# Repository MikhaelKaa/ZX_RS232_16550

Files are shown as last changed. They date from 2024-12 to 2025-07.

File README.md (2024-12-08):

# ZX RS232 на базе 16c550

## Описание
На данный момент сделан прототип.
top Прототип, вид на детали
top Прототип, вид на монтаж

## Программное обеспечение

## Схема подключения

## Начало работы

## Сборка устройства

## Лицензия

## Авторы

Оригинальная идея и порты - Михаил Кондратьев.

Прошивка cpld, схема и трассировка - Михаил Каа

## Благодарности

AnissimGimmervert

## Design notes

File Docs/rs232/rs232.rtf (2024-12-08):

Последовательный интерфейс RS-232. “Схема Кондратьева”.
ZX-MiltiCard v1.2 by Caro (Камиль Каримов).
Автор сего опуса jdigreze (Игорь Афонькин).
1. Общие положения
В состав многофункционального интерфейса ZX-MultiCard входит последовательный интерфейс стандарта RS-232C, включенный по схеме Кондратьева. В пространстве ввода-вывода компьютера ZX Spectrum устройство имеет базовый адрес #F8EF (63727).
Контроллер последовательного интерфейса является программируемым устройством, однако, следует отметить, что данная реализация не использует поддержку всех функций, заложенных в оригинале, построенном на базе кристалла i8250, используемого в семействе IBM PC, что, однако, не идет в ущерб в большинстве применений.
2. Описание внутренних регистров
С программной точки зрения, контроллер имеет несколько управляющих регистров, доступных через порты ввода-вывода компьютера ZX Spectrum. Всего в устройстве предусмотрено 8 портов ввода-вывода, два из которых оставлены для совместимости с оригиналом, и не влияют на работу контроллера.
Таблица соответствия регистров управления адресам портов ввода-вывода
№ рег. | Адрес | DLAB | Доступ | Наименование | Описание
0 | #F8EF | 0 | RW | REG_IO | Регистр данных
0 | #F8EF | 1 | W | REG_DIV_L | Младшая часть делителя
1 | #F9EF | 0 | - | REG_IRQ_ENABLE | Не используется
1 | #F9EF | 1 | W | REG_DIV_H | Старшая часть делителя
2 | #FAEF | 0 | - | REG_IRQ_IDENT | Не используется
3 | #FBEF | 0 | W | REG_LINE_CTRL | Управление конфигурацией
4 | #FCEF | 0 | W | REG_MDM_CTRL | Управление дополнительной линией
5 | #FDEF | 0 | R | REG_LINE_STATUS | Состояние приемопередатчика
6 | #FEEF | 0 | R | REG_MDM_STATUS | Состояние дополнительной линии
7 | #FFEF | 0 | - | REG_WORK_REG | Не используется
Примечание:
- Соответствие номера регистра адресу порта ввода-вывода устанавливается по формуле: RegisterAddress = BasicAddress + #100 x RegisterNumber, где RegisterAddress – адрес нужного регистра, BasicAddress – базовый адрес устройства (#F8EF), RegisterNumber – номер регистра для которого рассчитывается адрес;
- DLAB – 7 бит регистра управления конфигурацией (REG_LINE_CTRL);
- Порты #F8EF и #F9EF подключены к разным регистрам в зависимости от значения DLAB
- Режимы доступа к регистрам описаны условно

#F8EF - REG_IO (Регистр данных приемопередатчика)

Доступ к регистру осуществляется при DLAB = 0. При записи байта данных в этот регистр инициализируется передатчик последовательного интерфейса. Принятый байт данных получаем чтением из регистра. Перед работой с этим регистром требуется анализ регистра состояния приемопередатчика (#FDEF – REG_LINE_STATUS).

#F8EF – REG_DIV_L, #F9EF – REG_DIV_H (Регистры делителя скорости)

Доступ к регистрам осуществляется при DLAB = 1. Значение делителя определяется по формуле DIV = 115200/SpeedInBaud, где SpeedInBaud – требуемая скорость в бодах. Например, для скорости 9600 бод, получим значение 12 (#000C), таким образом, старшая часть делителя будет равна нулю (REG_DIV_H = #00), а младшая часть делителя будет равна 12 (REG_DIV_L = #0C).
#FBEF – REG_LINE_CTRL (Регистр управления конфигурацией)

Номера битов | Назначение
7 | DLAB – переключение регистров в портах #F8EF и #F9EF
6 | При “1” – имитация обрыва линии
5 | При “1” передаваемый бит четности устанавливается постоянным, зависит от b3..4
3..4 | При “00” и “10” – бит четности не рассчитывается, “01” - нечетное, “11” - четное
2 | Кол-во “стоп-битов”: при “0” = 1, при “1” = 1,5 в режиме 5 бит данных, иначе = 2
0..1 | Число битов данных: при “00” = 5, при “01” и “10” = 6, при “11” = 8
Основное назначение регистра конфигурации, это установка параметров приемопередатчика, но в данной реализации контроллера установка “нестандартных” параметров невозможна, соответственно этот регистр используется только для установки значения DLAB (бит 7), используемого для переключения регистров в портах #F8EF и #F9EF. Однако, для совместимости программного обеспечения с оригинальной версией устройства необходимо устанавливать параметры “8N1”, которым соответствует число #03, записанное в этот регистр после установки параметров скорости обмена в регистрах REG_DIV_L и REG_DIV_H.
#FCEF – REG_MDM_CTRL (Регистр управления модемом)

Номера битов | Назначение
7..5 | Не используются (равны “0”)
4 | Не используется. В оригинале при установке “1” включает диагностический режим
3 | Не используется. В оригинале при установке “1” разрешает прерывания RS-232C
2 | Не используется.
1 | Управление линией RTS (Запрос на передачу)
0 | Не используется. В оригинале управляет линией DTR (Готовность комп. к работе)
Как видно из таблицы, в данном регистре используется лишь функция управления запросом на передачу данных. При использовании описываемого устройства с модемом, после запроса на передачу, требуется ожидание готовности модема по линии CTS (см. REG_MDM_STATUS).
#FDEF – REG_LINE_STATUS (Регистр состояния приемопередатчика)

Номера битов | Назначение
7 | Не используется (Равен “0”)
6 | При “1” – регистр передатчика пуст. Нет обрабатываемых данных.
5 | При “1” - сдвиговый регистр передатчика пуст. Можно передавать следующий байт.
4 | Не используется. В оригинале: “1” при обнаружении обрыва линии.
3 | Не используется. В оригинале: “1” при неверном стоп-бите.
2 | Не используется. В оригинале: “1” при ошибке четности.
1 | Не используется. В оригинале: “1” при потере предыдущего байта.
0 | Устанавливается в “1” при успешном приеме данных.
Данный регистр используется для контроля готовности приемопередатчика к обмену данными. Бит 0, содержащий “1”, сигнализирует об успешном приеме байта данных извне, и будет находиться в таком состоянии, пока компьютер не прочитает данные из регистра данных приемопередатчика (REG_IO). Бит 5, содержащий “1”, сигнализирует об успешной отправке байта данных. Бит 6, содержащий “1”, сигнализирует об отсутствии данных для передачи. Несмотря на явные отличия в назначении битов 5 и 6 данного регистра, фактически они выполняют одну и ту же функцию – сигнализируют о готовности контроллера к передаче следующего байта данных.

#FEEF – REG_MDM_STATUS (Регистр состояния модема)

Номера битов | Назначение
7 | Не используется. В оригинале отображает состояние линии DCD.
6 | Не используется. В оригинале отображает состояние линии RI.
5 | Не используется. В оригинале отображает состояние линии DSR.
4 | Отображает состояние линии CTS (Готовность модема к передаче).
3 | Не используется. В оригинале отображает изменение состояния линии DCD.
2 | Не используется. В оригинале отображает изменение состояния линии RI.
1 | Не используется. В оригинале отображает изменение состояния линии DSR.
0 | Не используется. В оригинале отображает изменение состояния линии CTS.
В данной реализации для контроля состояния модема используется только линия CTS, сигнализирующая о готовности модема к приему данных, в соответствии с запросом по линии RTS (см. REG_MDM_CTRL).
К сожалению, из-за отсутствия контроля индикатора вызова - линии RI, использование контроллера, для организации сервера удаленного доступа, фактически невозможно.
3. Порядок инициализации
Для подготовки контроллера к обмену данными через интерфейс RS-232С с внешними устройствами необходимо выполнить следующие действия:
1. Установить бит 7 (DLAB) регистра управления конфигурацией (#FBEF – REG_LINE_CTRL);
2. Установить значение скорости обмена в регистры делителя скорости (#F8EF – REG_DIV_L и #F9EF – REG_DIV_H);
3. Установить параметры “8N1” в регистр управления конфигурацией, при этом сбросить бит 7 (DLAB).
Пример настройки контроллера на скорость обмена 9600 бод из режима BASIC-48:
10 LET register = 3: LET value = 128: GO SUB 1000
20 LET register = 0: LET value = 12: GO SUB 1000
30 LET register = 1: LET value =0: GO SUB 1000
40 LET register = 3: LET value = 3: GOSUB 1000
50 REM параметры установлены
…
1000 OUT (63727 + 256 * register), value: RETURN
…

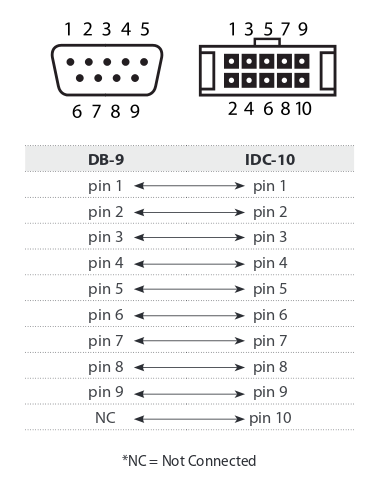
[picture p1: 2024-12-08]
Docs/media/plate9-pinout.png

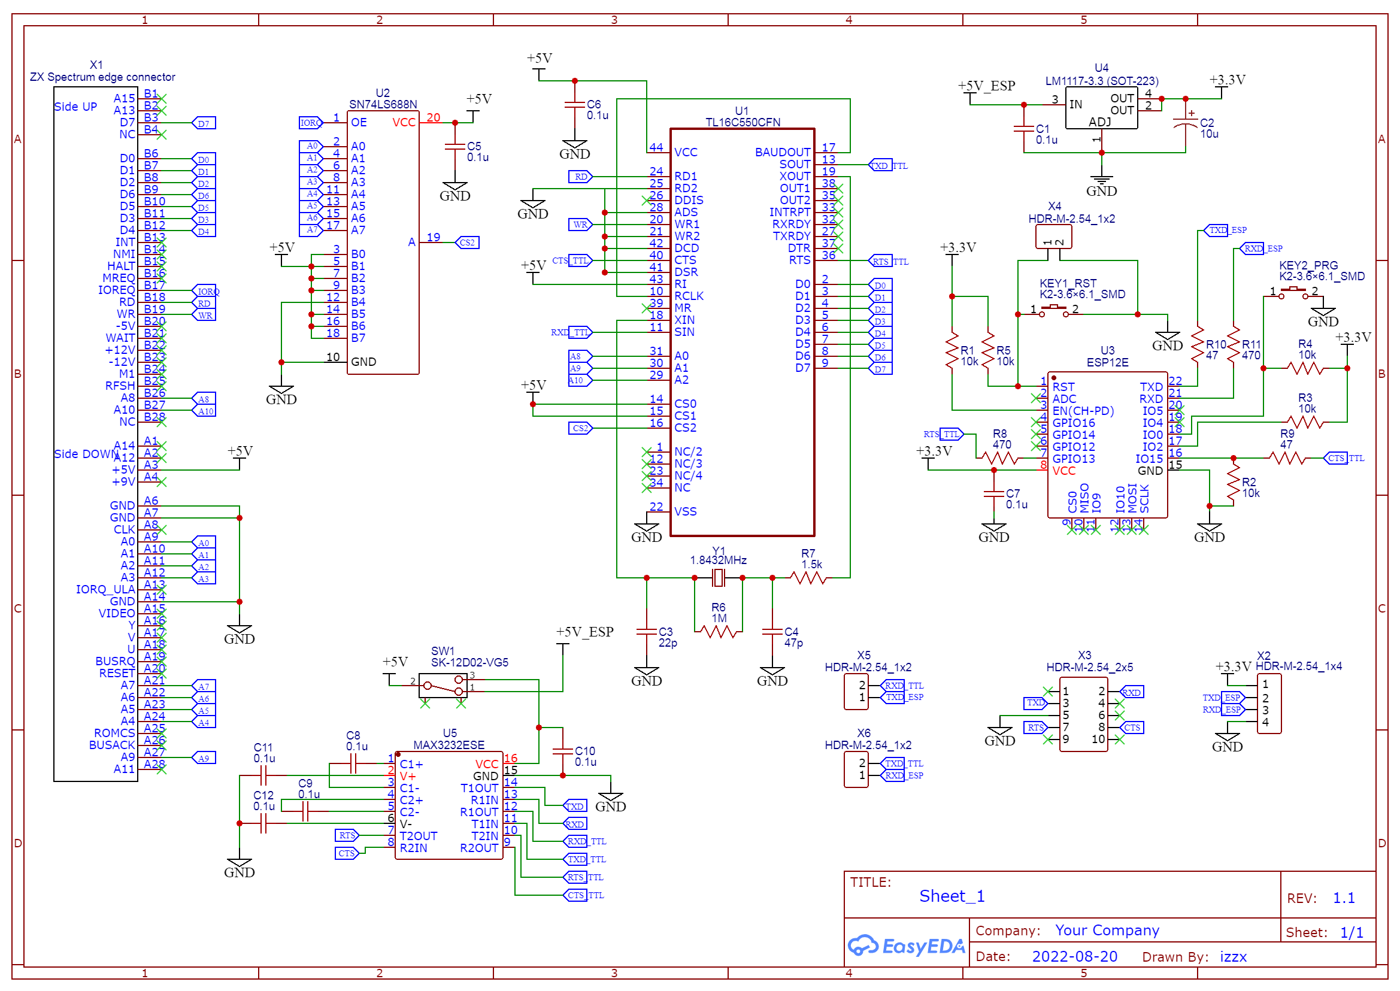
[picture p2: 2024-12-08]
Docs/media/Schematic_ZX WiFi_2022-08-20.png

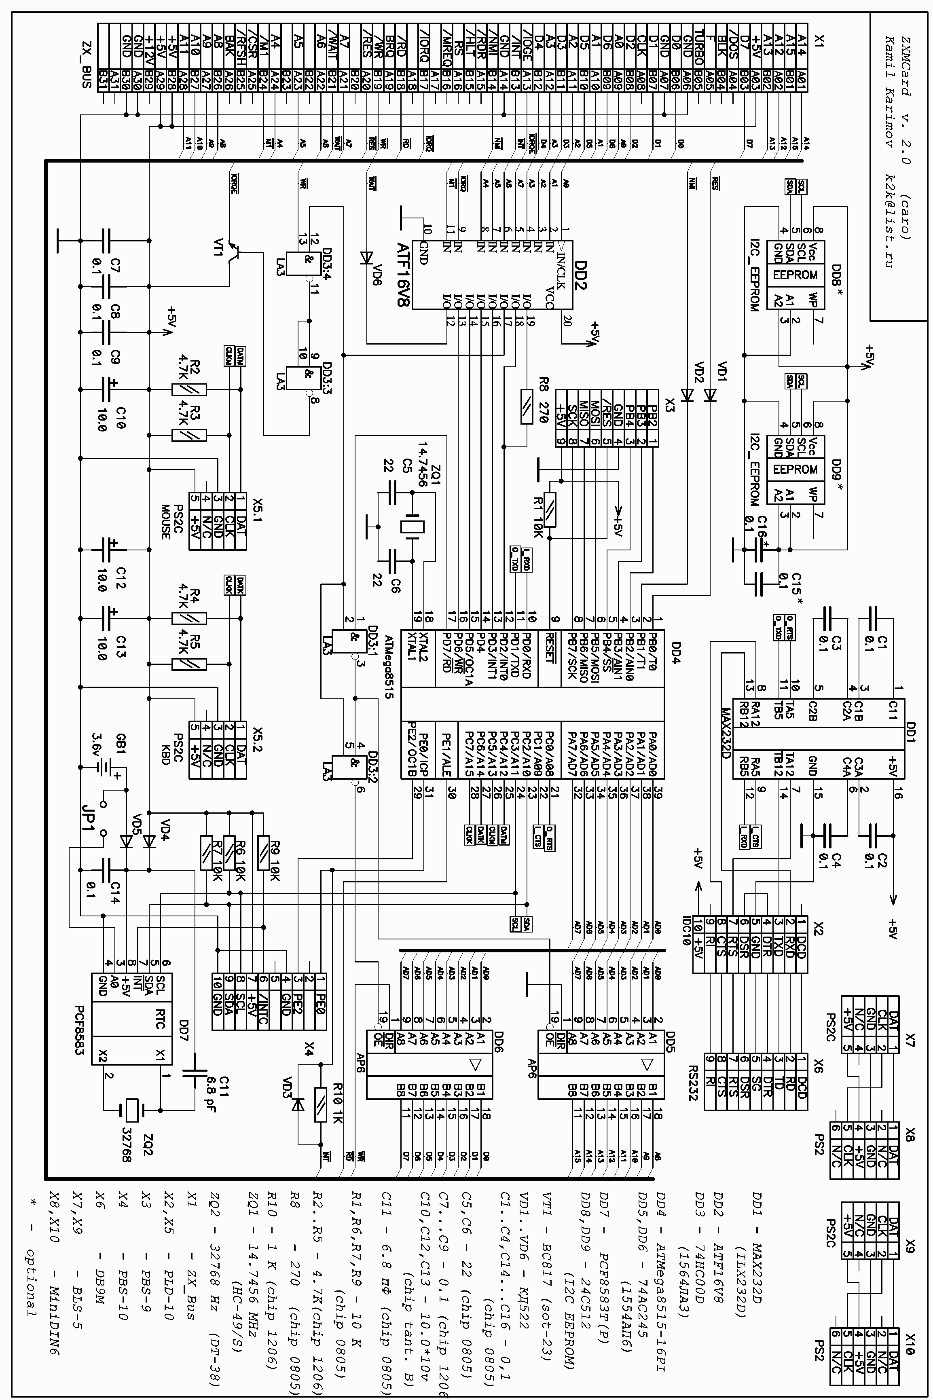
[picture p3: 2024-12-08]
Docs/media/zxmc20.png

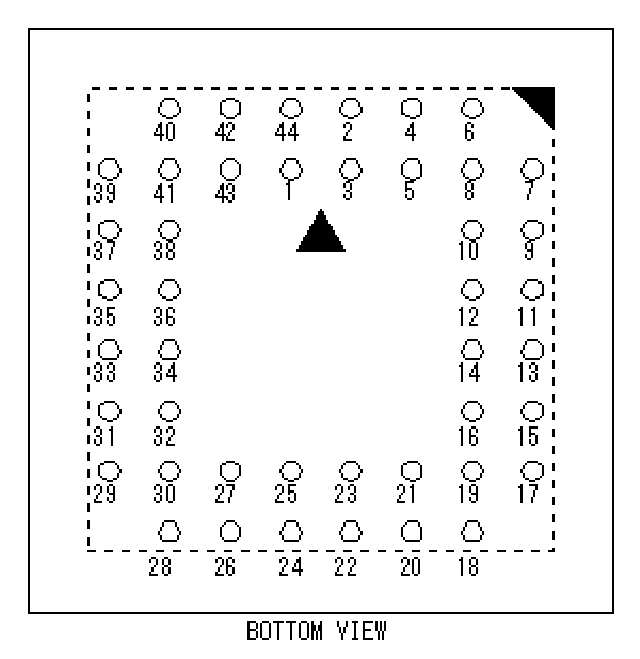
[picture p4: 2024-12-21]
Docs/media/PLCC_44_socket_01.png

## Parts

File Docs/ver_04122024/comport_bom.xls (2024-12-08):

Comment | Description | Designator | Footprint | LibRef | Quantity
0.1uF |  | C1, C2, C3 | C0805 | CapCer | 3
30пФ |  | C4 | C0805 | CapCer | 1
50пФ |  | C5 | C0805 | CapCer | 1
22uF |  | C6 | С1206 | CapCer | 1
10uF |  | C7, C8, C9, C10, C11, C12 | C0805 | CapCer | 6
AMS1117-3.3 |  | DA1 | SOT229P700X180-4N | AMS1117-3.3 | 1
EPM3032ALC44 | 44-Pin PLCC44 | DD1 | PLCC-44-R | EPM3032ALC44 | 1
MAX3232ID | 3-V to 5.5-V multichannel RS-232 line driver & receiver 16-SOIC -40 to 85 | DD2 | SOIC127P600X175-16N | MAX3232ID | 1
TL16C550CFN | ASYNCHRONOUS COMMUNICATIONS ELEMENT | DD3 | PLCC-44-R | TL16C550CFN | 1
1M |  | R1 | R0805 | Res | 1
1.5K |  | R2 | R0805 | Res | 1
4.7K |  | R3, R4, R5, R6 | R0805 | Res | 4
BC847 | NPN Transistor | VT1 | BC847 | BC847 | 1
BH-10 | 10 Position Total Dual Row 2.54 mm Pitch Straight Male Shrouded Box Header | XP1, XP2 | BH-10 | BH-10 | 2
1.8432 MHz | 1.8432 MHz | ZQ1 | XTAL_HC-49U | HC-49U_1.8432 | 1

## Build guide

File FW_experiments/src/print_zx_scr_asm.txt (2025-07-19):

#include "main.h"
// TODO: asm реализация печати в экран, рабочая. 
// Оставлена на будующее, когда настанет момент оптимизиции Си кода.
// x & y координаты знакомест
// _font_data шрифт который начинается с символа '!' (33)
void print(char x, char y, char* text) __naked {
    (void)(x);
    (void)(y);
    (void)(text);
    
    __asm
    ld iy, #2
    add iy, sp
    ld d, 0(iy)   ;x
    ld e, 1(iy)   ;y
    ld l, 2(iy)
    ld h, 3(iy)
print_string:
    //get_adr_on_screen
    ld a,d
    and #7
    rra
    rra
    rra
    rra
    or e
    ld e,a
    ld a,d
    and #24
    or #64
    ld d,a
print_string_loop:
    ld a, (hl)
    and a
    ret z
    push hl
    ld h, #0
    ld l, a
    add hl, hl
    add hl, hl
    add hl, hl
    ld bc, #_font_data - #256 ;
    add hl, bc
    push de
    call print_char
    pop de
    pop hl
    inc hl
    inc de
    jp print_string_loop
    ret

print_char:
    ld b, #8
pchar_loop:
    ld a, (hl)
    ld (de), a
    inc d
    inc hl
    djnz pchar_loop
    ret
    __endasm;
}

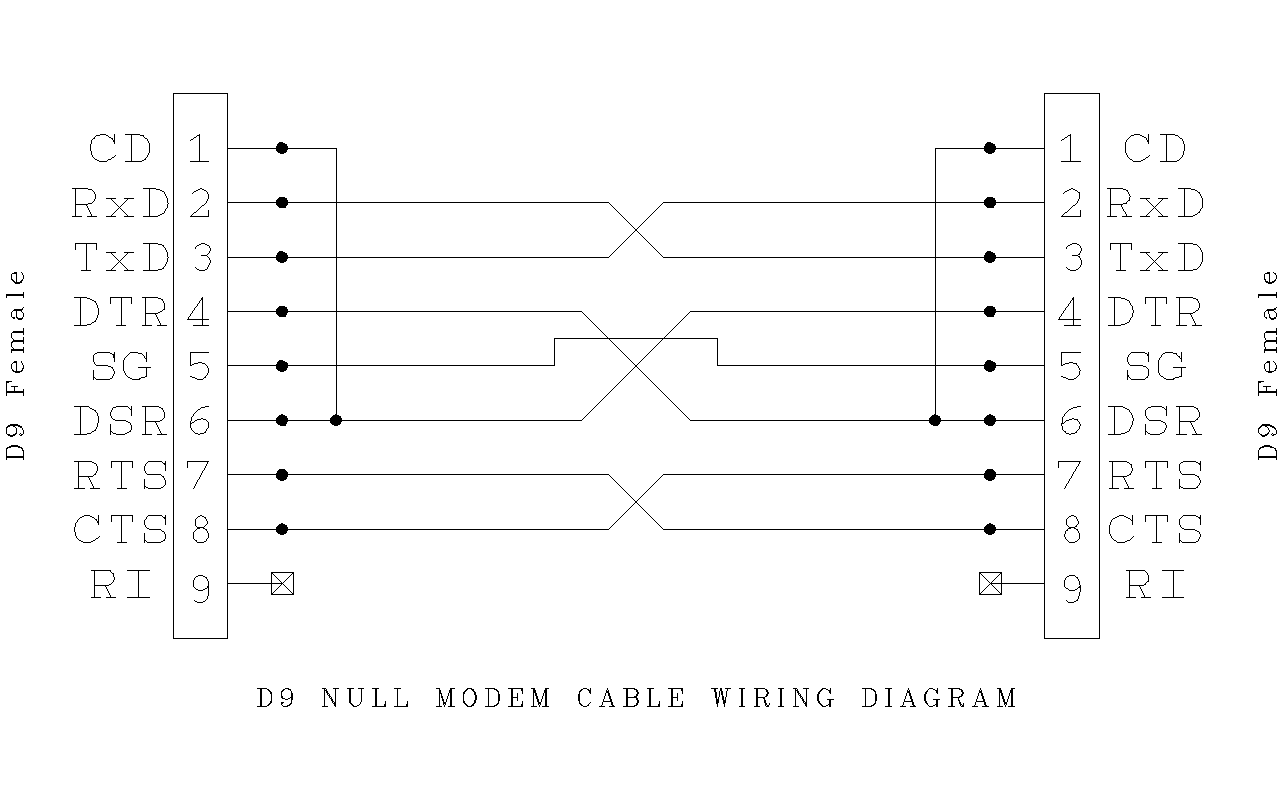
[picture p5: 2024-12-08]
Docs/media/D9_Null_Modem_Wiring.png

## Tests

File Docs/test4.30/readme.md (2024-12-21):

Tect 4.30 может детектировать голую 16550 на портах Кондратьева
System configuration:
Modem: Hayes-16550A

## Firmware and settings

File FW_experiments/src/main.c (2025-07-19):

// 15.04.2024 Михаил Каа

#include "main.h"
// #include "font.h"
#include "tl16c550.h"
#include "printf.h"
#include "ucmd.h"
#include "memory_man.h"
#include "z80_ports.h"
#include "defines.h"
#include "string_custom.h"
#include "printf_zx_scr.h"
#include "microrl.h"
#include "term_gxf.h"

#define SCREEN_START_ADR (0x4000)
#define SCREEN_SIZE ((256/8)*192)
#define SCREEN_ATR_SIZE (768)

void init_screen(void);


static microrl_t zx_rl;
static volatile uint8_t ucmd_zx_rx;
void ucmd_zx_print(const char * str) {
  fprintf(4, "%s", str);
}
  
void ucmd_zx_sigint(void) {
  fprintf(4, "ucmd_zx_sigint\r\n");
}

extern command_t cmd_list[];

int ucmd_zx_execute(int argc, char **argv) {
  int ret = 0;
  ret = ucmd_parse(cmd_list, argc, (const char **)argv);
  if(ret == UCMD_CMD_NOT_FOUND){
    static uint8_t gssu = 0;
    if(gssu++ < 6)  {
      fprintf(4, "unknown command");
      for(int i = 0; i < argc; i++) {
        fprintf(4, " %s", (char*)&argv[i][0]);
      }
      fprintf(4, ", try help\r\n");
    } else {
      gssu = 0;
      set_display_atrib(F_RED);
      fprintf(4, "GO SLEEP, STUPID USER!\r\n");
      resetcolor();
    }
  }
  return ret; 
}

void ucmd_zx_init(void) {
  ucmd_zx_rx = 0;
  microrl_init(&zx_rl, ucmd_zx_print);
  microrl_set_execute_callback(&zx_rl, (int (*)(int, const char * const*))ucmd_zx_execute);
  microrl_set_sigint_callback(&zx_rl, ucmd_zx_sigint);
  microrl_insert_char(&zx_rl, '\n');
}


char *screen = 0x4000;
char w = 0;
char i = 0;
// Глобальные переменные
volatile uint8_t key_current[8];
volatile uint8_t key_last[8] = {0xFF, 0xFF, 0xFF, 0xFF, 0xFF, 0xFF, 0xFF, 0xFF};
volatile uint8_t caps_shift = 0;
volatile uint8_t sym_shift = 0;

// Буфер для ASCII символов
#define KEYBUF_SIZE 32
volatile uint8_t keybuf[KEYBUF_SIZE];
volatile uint8_t keybuf_head = 0;
volatile uint8_t keybuf_tail = 0;

// Таблица преобразования клавиш в ASCII
const uint8_t keymap[8][5] = {
    // Row 0: SPACE, SYM, M, N, B (порт 0x7ffe)
    {' ',  0,  'm', 'n', 'b'},
    // Row 1: 0, 9, 8, 7, 6 (порт 0xeffe)
    {'0', '9', '8', '7', '6'},
    // Row 2: ENTER, L, K, J, H (порт 0xbffe)
    {'\n','l', 'k', 'j', 'h'},
    // Row 3: P, O, I, U, Y (порт 0xdffe)
    {'p', 'o', 'i', 'u', 'y'},
    // Row 4: 1, 2, 3, 4, 5 (порт 0xf7fe)
    {'1', '2', '3', '4', '5'},
    // Row 5: CAPS, Z, X, C, V (порт 0xfefe)
    { 0,  'z', 'x', 'c', 'v'},
    // Row 6: Q, W, E, R, T (порт 0xfbfe)
    {'q', 'w', 'e', 'r', 't'},
    // Row 7: A, S, D, F, G (порт 0xfdfe)
    {'a', 's', 'd', 'f', 'g'}
};


// Функция обработки символа
void process_key(uint8_t ascii) {
    // Добавление символа в кольцевой буфер
    uint8_t next_head = (keybuf_head + 1) % KEYBUF_SIZE;
    if(next_head != keybuf_tail) {
        keybuf[keybuf_head] = ascii;
        keybuf_head = next_head;
    }
}

// Преобразование позиции клавиши в ASCII
uint8_t key_to_ascii(uint8_t row, uint8_t bit) {
    uint8_t ch = keymap[row][bit];
    
    if (sym_shift) {
        // Обработка SYM SHIFT для цифр и специальных символов
        switch (ch) {
            case '0': return '_';
            case '1': return '!';
            case '2': return '@';
            case '3': return '#';
            case '4': return '$';
            case '5': return '%';
            case '6': return '&';
            case '7': return '\'';
            case '8': return '(';
            case '9': return ')';
            case 'k': return '+';
            case 'l': return '=';
            case 'm': return '?';
            case 'n': return ',';
            case 'b': return '*';
            case 'h': return '\\';
            case 'j': return '-';
            case 'u': return '<';
            case 'i': return '>';
            case 'o': return '[';
            case 'p': return ']';
            case 'y': return '{';
            case 't': return '}';
            case 'r': return '~';
            case 'e': return '^';
            case 'w': return '|';
            case 'q': return '`';
            case 'a': return ':';
            case 's': return ';';
            case 'd': return '"';
            case 'f': return '/';
            case 'g': return '=';
            case 'v': return '.';
            case 'c': return ',';
            case 'x': return '?';
            case 'z': return '!';
            default: break;
        }
    }
    
    // Обработка CAPS SHIFT для букв
    if (ch >= 'a' && ch <= 'z' && caps_shift) {
        return ch - 32; // Преобразование в верхний регистр
    }
    
    return ch;
}


void ucmd_zx_proc(void) {
  // Чтение из буфера
  if(keybuf_tail != keybuf_head) {
      uint8_t ascii = keybuf[keybuf_tail];
      keybuf_tail = (keybuf_tail + 1) % KEYBUF_SIZE;
      microrl_insert_char(&zx_rl, ascii);
  }
}

static volatile char irq_0x38_flag = 0;
static volatile char nmi_0x66_flag = 0;

char msg[] = "Hello world!!!";

int scr(int argc, char *argv[]) {
    for(int i = 0; i < argc; i++){
        fprintf(4, "%s ", argv[i]);
    }
    fprintf(4, "\r\n");
    return 0;
}

int reset(int argc, char *argv[]) {
    (void)(argc);
    (void)(argv);
    
    __asm
    jp 0
    __endasm;
    return -1;
}

// Пример cmd_list.
command_t cmd_list[] = {
  {
    .cmd  = "help",
    .help = "print available commands with their help text",
    .fn   = print_help_cb,
  },
  {
    .cmd  = "mem",
    .help = "mem",
    .fn   = ucmd_mem,
  },
  {
    .cmd  = "port",
    .help = "port",
    .fn   = ucmd_port,
  },
  {
    .cmd  = "scr",
    .help = "scr",
    .fn   = scr,
  },
    {
    .cmd  = "reset",
    .help = "reset",
    .fn   = reset,
  },
  {0} // null list terminator DON'T FORGET THIS!
};
void main() {
    uart_init();
    clear_screen();
    init_screen();
    printf("\r\n\r\n***********************\r\n");
    printf("init 0\r\n");
    printf("Its work!!!\r\n");
    printf("test d %d\r\n", 42);
    printf("test s %s\r\n", msg);
    printf("test c %c\r\n", 'U');
    printf("test s&d %s %d\r\n", msg, 73);
    ucmd_default_init();
    ucmd_zx_init();
    while(1) {
        ucmd_default_proc();

        if(irq_0x38_flag == 1) {
            irq_0x38_flag = 0;

            for(uint8_t row = 0; row < 8; row++) {
                uint8_t current = key_current[row];
                uint8_t last = key_last[row];
                uint8_t diff = current ^ last;
                
                if(diff) {
                    for(uint8_t bit = 0; bit < 5; bit++) {
                        uint8_t mask = 1 << bit;
                        
                        // Проверка изменения бита
                        if(diff & mask) {
                            // Обнаружено нажатие (0 - нажата)
                            if(!(current & mask)) {
                                uint8_t ascii = key_to_ascii(row, bit);
                                
                                // Игнорировать специальные клавиши (0 в таблице)
                                if(ascii) {
                                    process_key(ascii);
                                }
                            }
                        }
                    }
                    key_last[row] = current;
                }
            }
        }

        ucmd_zx_proc();

        if(nmi_0x66_flag) {
            nmi_0x66_flag = 0;
            *(screen + 2) = i;
            printf("nmi\r\n");
        }
    }
}

void init_screen(void) {
    port_0x00fe = 7;
    for (unsigned int i = SCREEN_START_ADR; i < (SCREEN_START_ADR+SCREEN_SIZE); i++) {
        *((char *)i) = 0;
    } 
    for (unsigned int i = SCREEN_START_ADR+SCREEN_SIZE; i < (SCREEN_START_ADR+SCREEN_SIZE+SCREEN_ATR_SIZE); i++) {
        *((char *)i) = 4;
    }
    port_0x00fe = 0;
}

// Обработчик прерывания
volatile void irq_0x38(void) {
  irq_0x38_flag = 1;

  // Чтение всех строк клавиатуры
  key_current[0] = port_0x7ffe & 0x1F;
  key_current[1] = port_0xeffe & 0x1F;
  key_current[2] = port_0xbffe & 0x1F;
  key_current[3] = port_0xdffe & 0x1F;
  key_current[4] = port_0xf7fe & 0x1F;
  key_current[5] = port_0xfefe & 0x1F;
  key_current[6] = port_0xfbfe & 0x1F;
  key_current[7] = port_0xfdfe & 0x1F;

  // Обновление модификаторов
  caps_shift = !(key_current[5] & 0x01); // CAPS SHIFT в row5, bit0
  sym_shift = !(key_current[0] & 0x02);  // SYM SHIFT в row0, bit1
}

volatile void nmi_0x66(void) {
    nmi_0x66_flag = 1;
}

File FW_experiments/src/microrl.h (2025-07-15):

#ifndef _MICRORL_H_
#define _MICRORL_H_

#include "config.h"

#define true  1
#define false 0

#define NULL 0

 /* define the Key codes */
#define KEY_NUL 0 /**< ^@ Null character */
#define KEY_SOH 1 /**< ^A Start of heading, = console interrupt */
#define KEY_STX 2 /**< ^B Start of text, maintenance mode on HP console */
#define KEY_ETX 3 /**< ^C End of text */
#define KEY_EOT 4 /**< ^D End of transmission, not the same as ETB */
#define KEY_ENQ 5 /**< ^E Enquiry, goes with ACK; old HP flow control */
#define KEY_ACK 6 /**< ^F Acknowledge, clears ENQ logon hand */
#define KEY_BEL 7 /**< ^G Bell, rings the bell... */
#define KEY_BS  8 /**< ^H Backspace, works on HP terminals/computers */
#define KEY_HT  9 /**< ^I Horizontal tab, move to next tab stop */
#define KEY_LF  10  /**< ^J Line Feed */
#define KEY_VT  11  /**< ^K Vertical tab */
#define KEY_FF  12  /**< ^L Form Feed, page eject */
#define KEY_CR  13  /**< ^M Carriage Return*/
#define KEY_SO  14  /**< ^N Shift Out, alternate character set */
#define KEY_SI  15  /**< ^O Shift In, resume defaultn character set */
#define KEY_DLE 16  /**< ^P Data link escape */
#define KEY_DC1 17  /**< ^Q XON, with XOFF to pause listings; "okay to send". */
#define KEY_DC2 18  /**< ^R Device control 2, block-mode flow control */
#define KEY_DC3 19  /**< ^S XOFF, with XON is TERM=18 flow control */
#define KEY_DC4 20  /**< ^T Device control 4 */
#define KEY_NAK 21  /**< ^U Negative acknowledge */
#define KEY_SYN 22  /**< ^V Synchronous idle */
#define KEY_ETB 23  /**< ^W End transmission block, not the same as EOT */
#define KEY_CAN 24  /**< ^X Cancel line, MPE echoes !!! */
#define KEY_EM  25  /**< ^Y End of medium, Control-Y interrupt */
#define KEY_SUB 26  /**< ^Z Substitute */
#define KEY_ESC 27  /**< ^[ Escape, next character is not echoed */
#define KEY_FS  28  /**< ^\ File separator */
#define KEY_GS  29  /**< ^] Group separator */
#define KEY_RS  30  /**< ^^ Record separator, block-mode terminator */
#define KEY_US  31  /**< ^_ Unit separator */

#define KEY_DEL 127 /**< Delete (not a real control character...) */



// direction of history navigation
#define _HIST_UP   0
#define _HIST_DOWN 1
// esc seq internal codes
#define _ESC_BRACKET  1
#define _ESC_HOME     2
#define _ESC_END      3

#ifdef _USE_HISTORY
// history struct, contain internal variable
// history store in static ring buffer for memory saving
typedef struct {
	char ring_buf [_RING_HISTORY_LEN];
	int begin;
	int end;
	int cur;
} ring_history_t;
#endif

// microrl struct, contain internal library data
typedef struct {
#ifdef _USE_ESC_SEQ
	char escape_seq;
	char escape;
#endif
#if (defined(_ENDL_CRLF) || defined(_ENDL_LFCR))
	char tmpch;
#endif
#ifdef _USE_HISTORY
	ring_history_t ring_hist;          // history object
#endif
	char * prompt_str;                 // pointer to prompt string
	char cmdline [_COMMAND_LINE_LEN];  // cmdline buffer
	int cmdlen;                        // last position in command line
	int cursor;                        // input cursor
	int (*execute) (int argc,  char *  * argv );            // ptr to 'execute' callback
	char ** (*get_completion) (int argc,  char *  * argv ); // ptr to 'completion' callback
	void (*print) (const char *);                                     // ptr to 'print' callback
#ifdef _USE_CTLR_C
	void (*sigint) (void);
#endif
} microrl_t;

// init internal data, calls once at start up
void microrl_init (microrl_t * pThis, void (*print)(const char*));

// set echo mode (true/false), using for disabling echo for password input
// echo mode will enabled after user press Enter.
void microrl_set_echo (int);

// set pointer to callback complition func, that called when user press 'Tab'
// callback func description:
//   param: argc - argument count, argv - pointer array to token string
//   must return NULL-terminated string, contain complite variant splitted by 'Whitespace'
//   If complite token found, it's must contain only one token to be complitted
//   Empty string if complite not found, and multiple string if there are some token
void microrl_set_complete_callback (microrl_t * pThis, char ** (*get_completion)(int, const char* const*));

// pointer to callback func, that called when user press 'Enter'
// execute func param: argc - argument count, argv - pointer array to token string
void microrl_set_execute_callback (microrl_t * pThis, int (*execute)(int, const char* const*));

// set callback for Ctrl+C terminal signal
#ifdef _USE_CTLR_C
void microrl_set_sigint_callback (microrl_t * pThis, void (*sigintf)(void));
#endif

// insert char to cmdline (for example call in usart RX interrupt)
void microrl_insert_char (microrl_t * pThis, int ch);

#endif

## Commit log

2024-12-08 add: start new repo
    [comport.PrjPCB, comport_bom.xls, main.SchDoc]
2024-12-08 add: добавлена прошивка прототипа.
2024-12-14 fix: убрал глитч на CS
2024-12-14 add: Добавлены експерименты с 16550 на Си
2024-12-21 add: Захват детекта тестом 4.30 чипа 16550. Изменения в прошивке 3032 -> временный фильт глитчей.
2025-05-03 fix: Исправлен makefile
2025-05-03 fix: Исправлена опечатка копипасты
2025-05-04 fix: Шрифт перенесен в ассеты.
2025-07-12 fix: Коментарии к иниту 16550
    [tl16c550.c]
2025-07-14 fix: printf (getchar putchar)
    [main.c, tl16c550.c]
2025-07-14 add: Криво и косо, но оно (консолька) заработало!
2025-07-15 fix: рефакторинг
2025-07-15 add: Чтение и запись портов
2025-07-15 add: кривой и косой вывод на экран
2025-07-15 fix: косметические изменения.
2025-07-18 add: Обработка клавиатуры + невероятное количество глючности.
2025-07-18 fix: Странное, но рабочее. Требует сильного рефакторинга.
    [main.c, printf.c]
2025-07-19 add: пародия на терминал на экране zx с скроллом. Какбы работает. В копилку кусков кода на рефакторинг.
